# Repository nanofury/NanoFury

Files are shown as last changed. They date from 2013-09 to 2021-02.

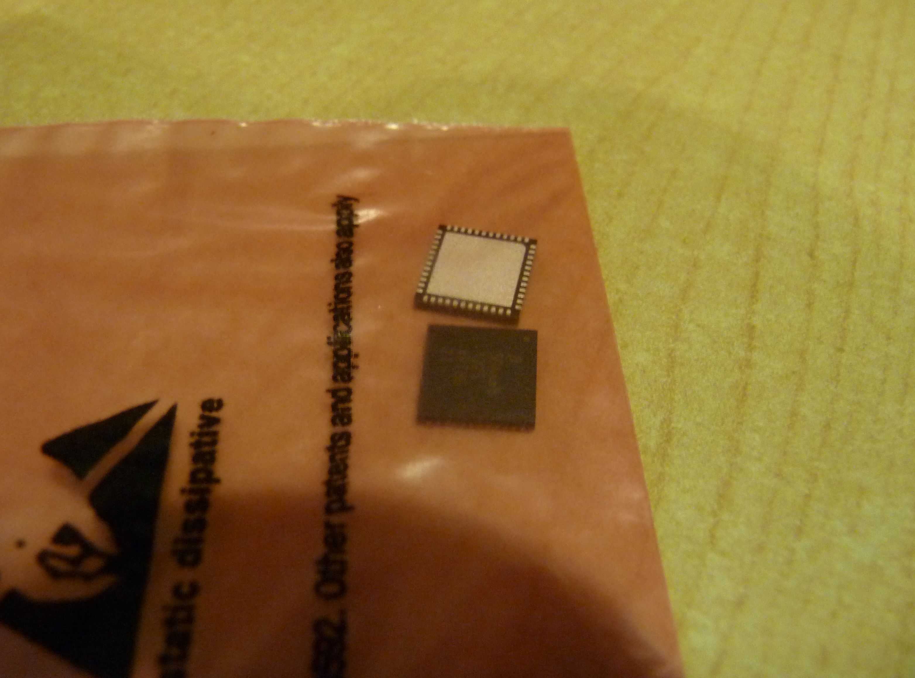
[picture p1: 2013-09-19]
NF1/docs/bitfury/img/P1060710m.jpg

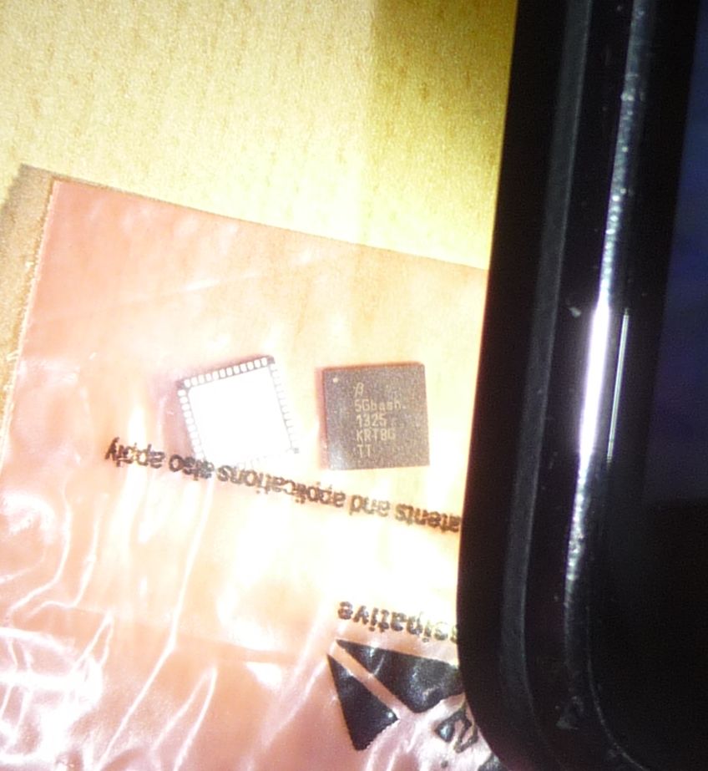
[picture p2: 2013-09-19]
NF1/docs/bitfury/img/P1060713m.jpg

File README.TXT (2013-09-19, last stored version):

NanoFury
========

NanoFury Bitcoin ASIC Miner Project

WARNING:

  This project is incomplete and in progress. There may be errors, mistakes, incomplete portions at this time. Do NOT use these project files to order circuit boards until they have been finished and confirmed to work.

  See LICENSE and COPYING files for terms and warranty disclaimer.

  See RELEASE NOTES for known problems, and issues.

SUMMARY:

  This is an open source effort to design and build a Bitcoin mining board based on the BitFury ASIC. Initially the goal is to have a simple USB-to-BitFury interface. The final goal is this design to be used as a base for a board with multiple ASIC chips as BitFury's chips are easily chain-able. The only limitation would be from the speed of the SPI bus which is estimated at this time to be sufficient for up to 64 chips.

STATUS:

  This project is under active development.

  A new cgminer-nanofury repo will be created for development with only changed files echoed here in the cgminer directory.

TODO:

  Adapt Kerry Wong's MCP2210 library for use with cgminer (unless Con Kolivas recommends another library - which may happen rather sooner than later as he mentioned that he has his own USB-HID library)

  Integration and debugging of the MCP2210 and BitFury chips.

  Stress testing and reliability in over-clocking situations.

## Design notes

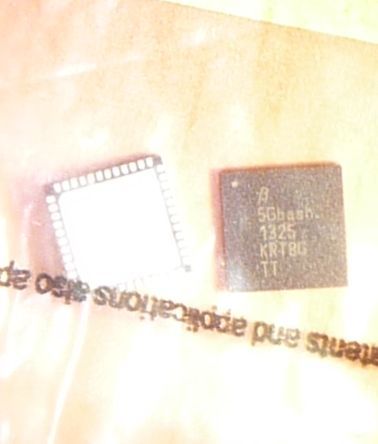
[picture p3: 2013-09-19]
NF1/docs/bitfury/img/P1060713a.jpg

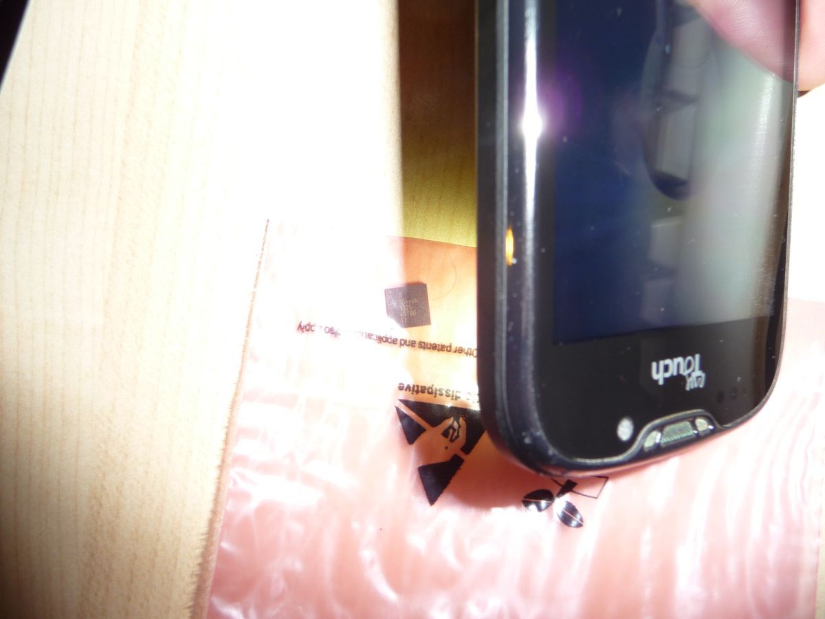
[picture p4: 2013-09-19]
NF1/docs/bitfury/img/P1060712m.jpg

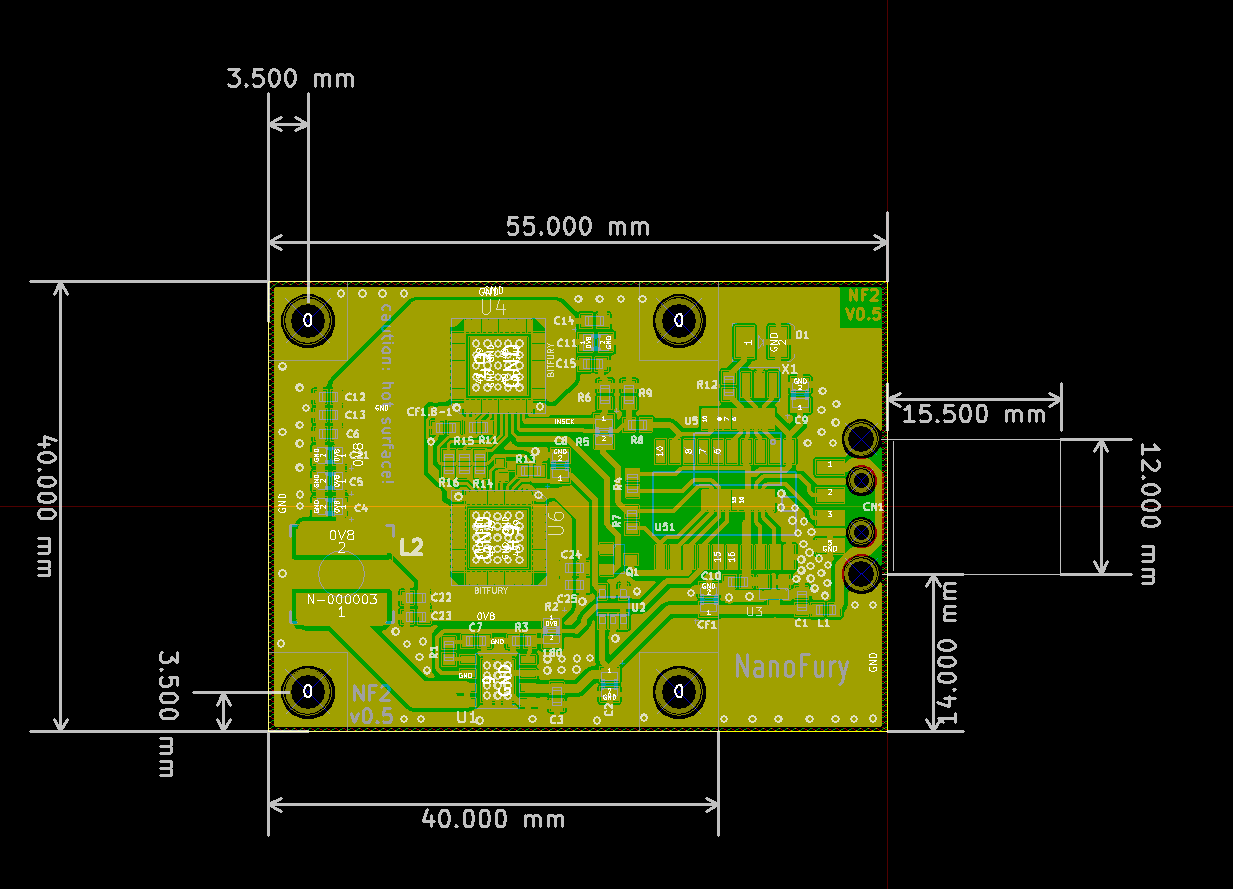
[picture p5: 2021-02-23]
NF1/kicad/NF2-MCP-V05/NF2-05-Dimensions.png

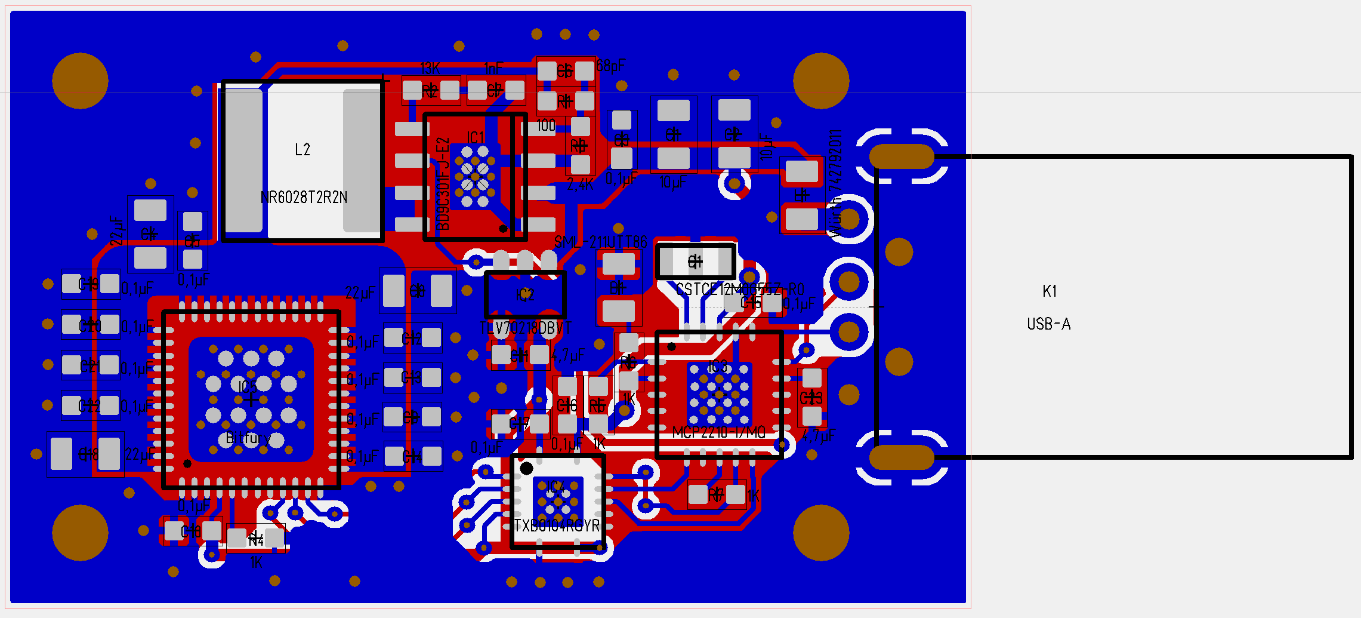
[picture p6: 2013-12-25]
NF1/kicad/NF1-MCP-V06-2/Nanofury2_Layout.PNG

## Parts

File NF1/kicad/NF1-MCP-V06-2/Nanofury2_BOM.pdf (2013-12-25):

Pos Anzahl Name | Wert | Gehäuse
1 | 1 | R1 | 100R/0,1%/25ppm | 0603_NORM | A102330CT-ND
2 | 4 | R4,R5,R6,R7 | 1K/1% | 0603_NORM | P1.00KHCT-ND
3 | 1 | R2 | 13K/1% | 0603_NORM | P13.0KHCT-ND
4 | 1 | R3 | 2,4K/0,1%/25ppm | 0603_NORM | P2.4KDBCT-ND
5 | 1 | L1 | | 0805_NORM | 732-4635-1-ND
6 | 2 | C11, C23 | 4,7µF/10V/X6S | 0603_NORM | 445-7442-1-ND
7 | 2 | C1,C2 | 10µF/25V/X6S | 0805_NORM | 445-14484-1-ND
8 | 1 | C7 | 1nF/50V/C0G | 0603_NORM | 1276-1091-1-ND
9 | 14 | C3,C5,C9,C10,C12,C13,C14,C15,C16,C17,C19,C20,C21,C22 | 0,1µF/16V/X7R | 0603_NORM | 1276-1005-1-ND
10 | 3 | C4,C8,C18 | 22µF/4V/X7U | 0805_NORM | 490-6468-1-ND
11 | 1 | C6 | 68pF/50V/C0G | 0603_NORM | 311-1067-1-ND
12 | 1 | IC1 | BD9C301FJ-E2 | SO8_SOT96-1_EP | 846-1117-1-ND
13 | 1 | IC5 | | QFN48/BITFURY | vorhanden
14 | 1 | IC3 | MCP2210-I/MQ | QFN20(5X5) | MCP2210-I/MQ-ND
15 | 1 | L2 | NR6028T2R2N | NR6028 | 587-2098-1-ND
16 | 1 | D1 | SML-211UTT86 | 0805_NORM | 511-1292-1-ND
17 | 1 | IC2 | TLV70218DBVT | SOT23/5 | 296-27889-1-ND
18 | 1 | IC4 | TXB0104RGYR | QFN20/TXB0104 | 296-21930-1-ND
19 | 1 | Q1 | CSTCE12M0G55Z-R0 CSTCE12M0G55Z-R0 | 490-1220-1-ND
20 | 1 | Leiterplatte
21 | 1
22 | 2 | | SK551-50-SA

DigiKey

Würth 742792011

Bitfury

USB-A-Stecker, PCB-Montage Kühlkörper Fischer-Electronic

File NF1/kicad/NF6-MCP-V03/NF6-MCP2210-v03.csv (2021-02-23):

ref | value | datasheet | footprint | Field1 | Field2 | Field3 | Field4 | Field5 | Field6 | Field7 | Field8
BF0 | BITFURY |  | QFN48
BF1 | BITFURY |  | QFN48
BF2 | BITFURY |  | QFN48
BF3 | BITFURY |  | QFN48
BF4 | BITFURY |  | QFN48
BF5 | BITFURY |  | QFN48
C1 | 100nF |  | 0603
C01 | 4.7uF |  | 0805 |  | AMK212AC6226MG
C02 | 100nF |  | 0603
C03 | 100nF |  | 0603
C04 | 100nF |  | 0603
C9 | 4.7uF/10V |  | 0805 |  | LMK212AB7106MG
C10 | 100n |  | 0603
C11 | 4.7uF |  | 0805 |  | AMK212AC6226MG
C12 | 100nF |  | 0603
C13 | 100nF |  | 0603
C14 | 100nF |  | 0603
C21 | 4.7uF |  | 0805 |  | AMK212AC6226MG
C22 | 100nF |  | 0603
C23 | 100nF |  | 0603
C24 | 100nF |  | 0603
C31 | 4.7uF |  | 0805 |  | AMK212AC6226MG
C32 | 100nF |  | 0603
C33 | 100nF |  | 0603
C34 | 100nF |  | 0603
C41 | 4.7uF |  | 0805 |  | AMK212AC6226MG
C42 | 100nF |  | 0603
C43 | 100nF |  | 0603
C44 | 100nF |  | 0603
C51 | 4.7uF |  | 0805 |  | AMK212AC6226MG
C52 | 100nF |  | 0603
C53 | 100nF |  | 0603
C54 | 100nF |  | 0603
C_REF0 | 100nF |  | 0603
C_REF1 | 100nF |  | 0603
C_REF2 | 100nF |  | 0603
C_REF3 | 100nF |  | 0603
C_REF4 | 100nF |  | 0603
C_REF5 | 100nF |  | 0603
CF1 | 4.7uF/10V |  | 0805 |  | C2012X6S0J226M085AC
CN1 | USB-A | 1001-011-01101.pdf | CNC-1001-011-01101 | 1001-011-01101.pdf | 1001-011-01101
D1 | LED | LO_LS_LY_T67K_Pb_free.pdf | 2PLCC | LO_LS_LY_T67K_Pb_free.pdf | LY T67K-J2M1-26-Z
F1 | FUSE 4A |  | 0603
L1 | 10R@100MHz/6A |  | 0603 |  | CIB10P100NC (or ACML-0603-060)
P0 | TP | ~ | ~ | ~
P1 | TP | ~ | ~ | ~
P2 | TP | ~ | ~ | ~
P3 | TP | ~ | ~ | ~
P4 | TP | ~ | ~ | ~
P5 | TP | ~ | ~ | ~
P51 | TP | ~ | ~ | ~
P52 | TP | ~ | ~ | ~
P53 | TP | ~ | ~ | ~
Q1 | BSS138L | BSS138LT1-D.pdf | SOT23 | BSS138LT1-D.pdf | BSS138LT3G
Q2 | Si2333CDS | si2333cd.pdf | SOT23 | si2333cd.pdf
R1 | 1k |  | 0603
R2 | 1k |  | 0603
R3 | 1k |  | 0603
R04 | 1k |  | 0603
R4 | 2k |  | 0603
R05 | 1k |  | 0603
R5 | 2k |  | 0805
R6 | 20k |  | 0603
R7 | 1k |  | 0603
R8 | 2K |  | 0603
R9 | 20k |  | 0603
R11 | 1k |  | 0603
R12 | 1k |  | 0603
R13 | 1k |  | 0603
R14 | 1k |  | 0603
R15 | 1k |  | 0603
R21 | 1k |  | 0603
R22 | 1k |  | 0603
R23 | 1k |  | 0603
R24 | 1k |  | 0603
R25 | 1k |  | 0603
R31 | 1k |  | 0603
R32 | 1k |  | 0603
R33 | 1k |  | 0603
R34 | 1k |  | 0603
R35 | 1k |  | 0603
R41 | 1k |  | 0603
R42 | 1k |  | 0603
R43 | 1k |  | 0603
R51 | 1k |  | 0603
R52 | 1k |  | 0603
R53 | 1k |  | 0603
R54 | 1k |  | 0603
R55 | 1k |  | 0603
U3 | LDO - 3.3V | 202250A.pdf | SOT23 | 202250A.pdf | MCP1700T-3302E/TT
U5 | MCP2210-I/SS | 22288A.pdf | SSOP-20 | 22288A.pdf
U51 | MCP2210-I/SO | 22288A.pdf | SOIC20 | 22288A.pdf
X1 | 12MHz | p16e.pdf | CSTCE_G15C | p16e.pdf | CSTCE12M0G55Z-R0

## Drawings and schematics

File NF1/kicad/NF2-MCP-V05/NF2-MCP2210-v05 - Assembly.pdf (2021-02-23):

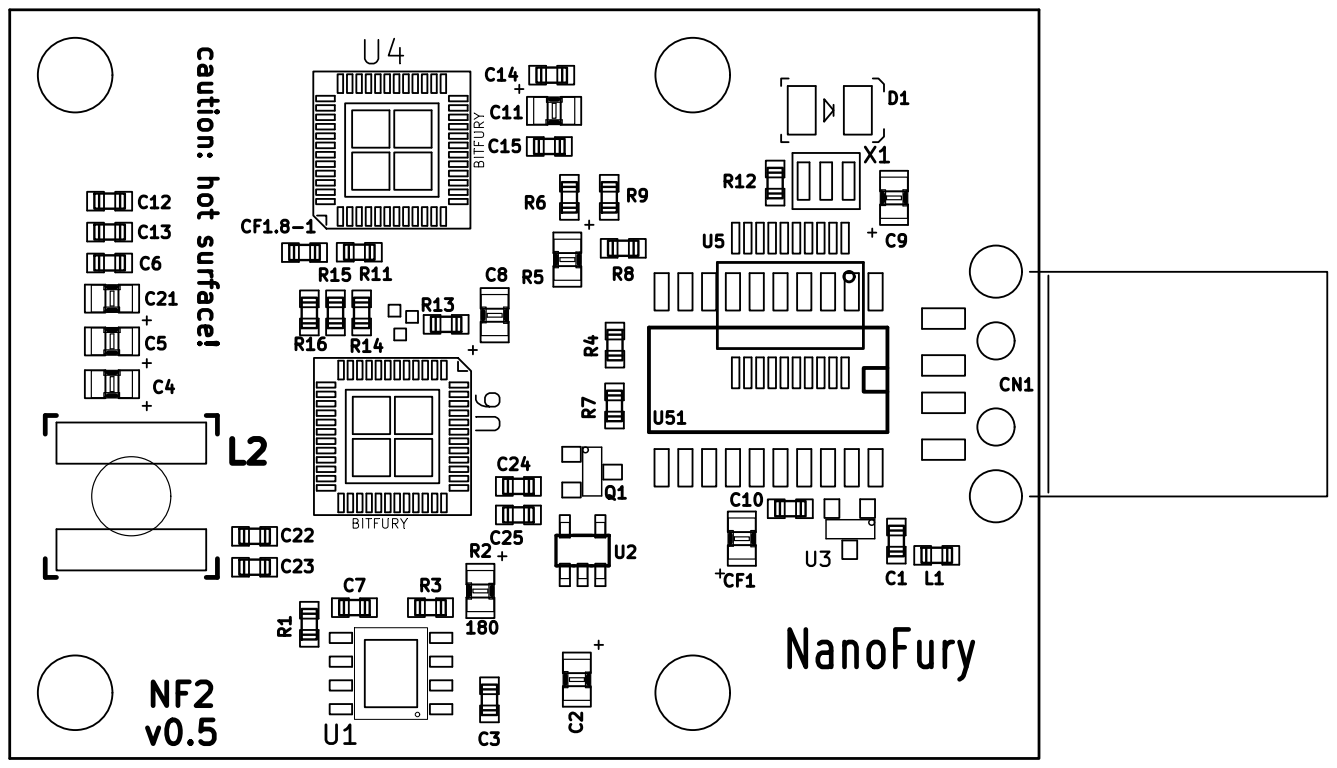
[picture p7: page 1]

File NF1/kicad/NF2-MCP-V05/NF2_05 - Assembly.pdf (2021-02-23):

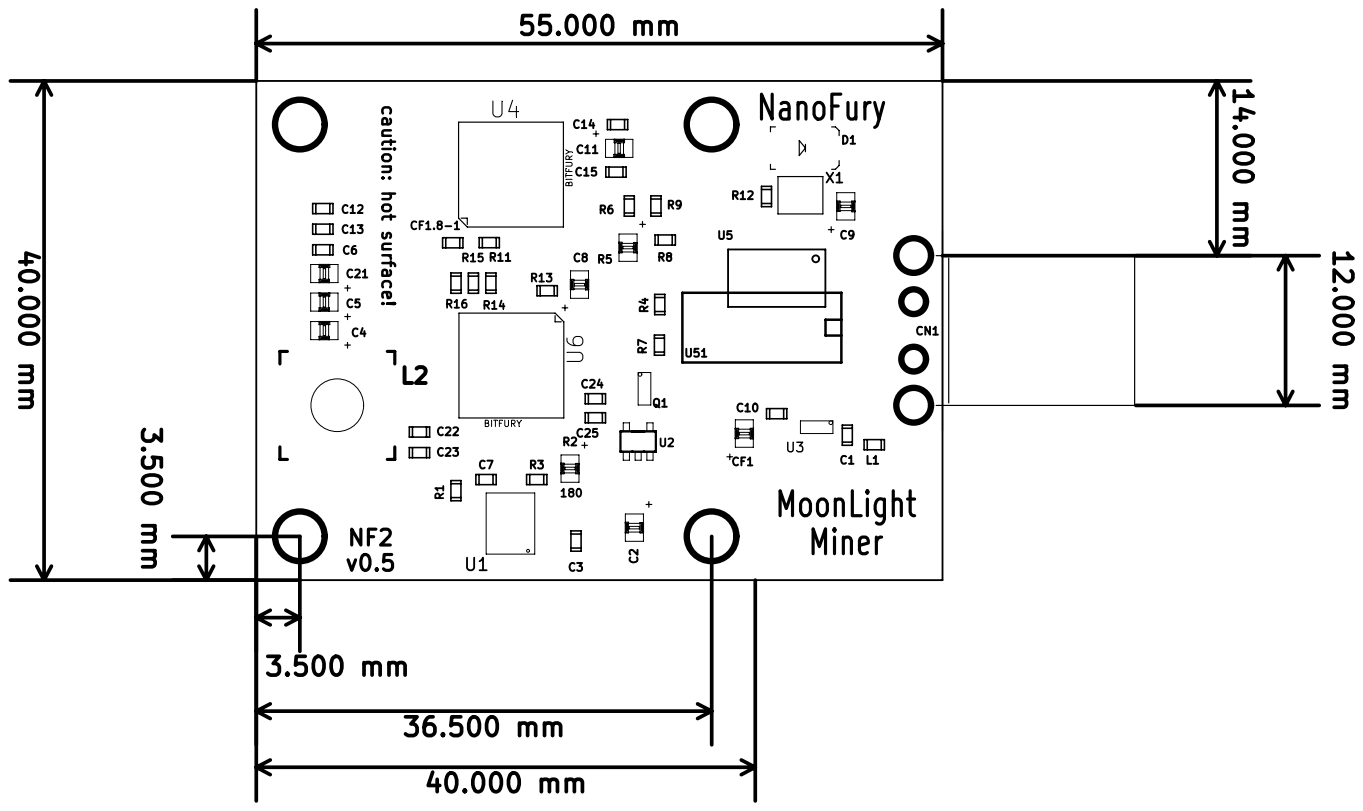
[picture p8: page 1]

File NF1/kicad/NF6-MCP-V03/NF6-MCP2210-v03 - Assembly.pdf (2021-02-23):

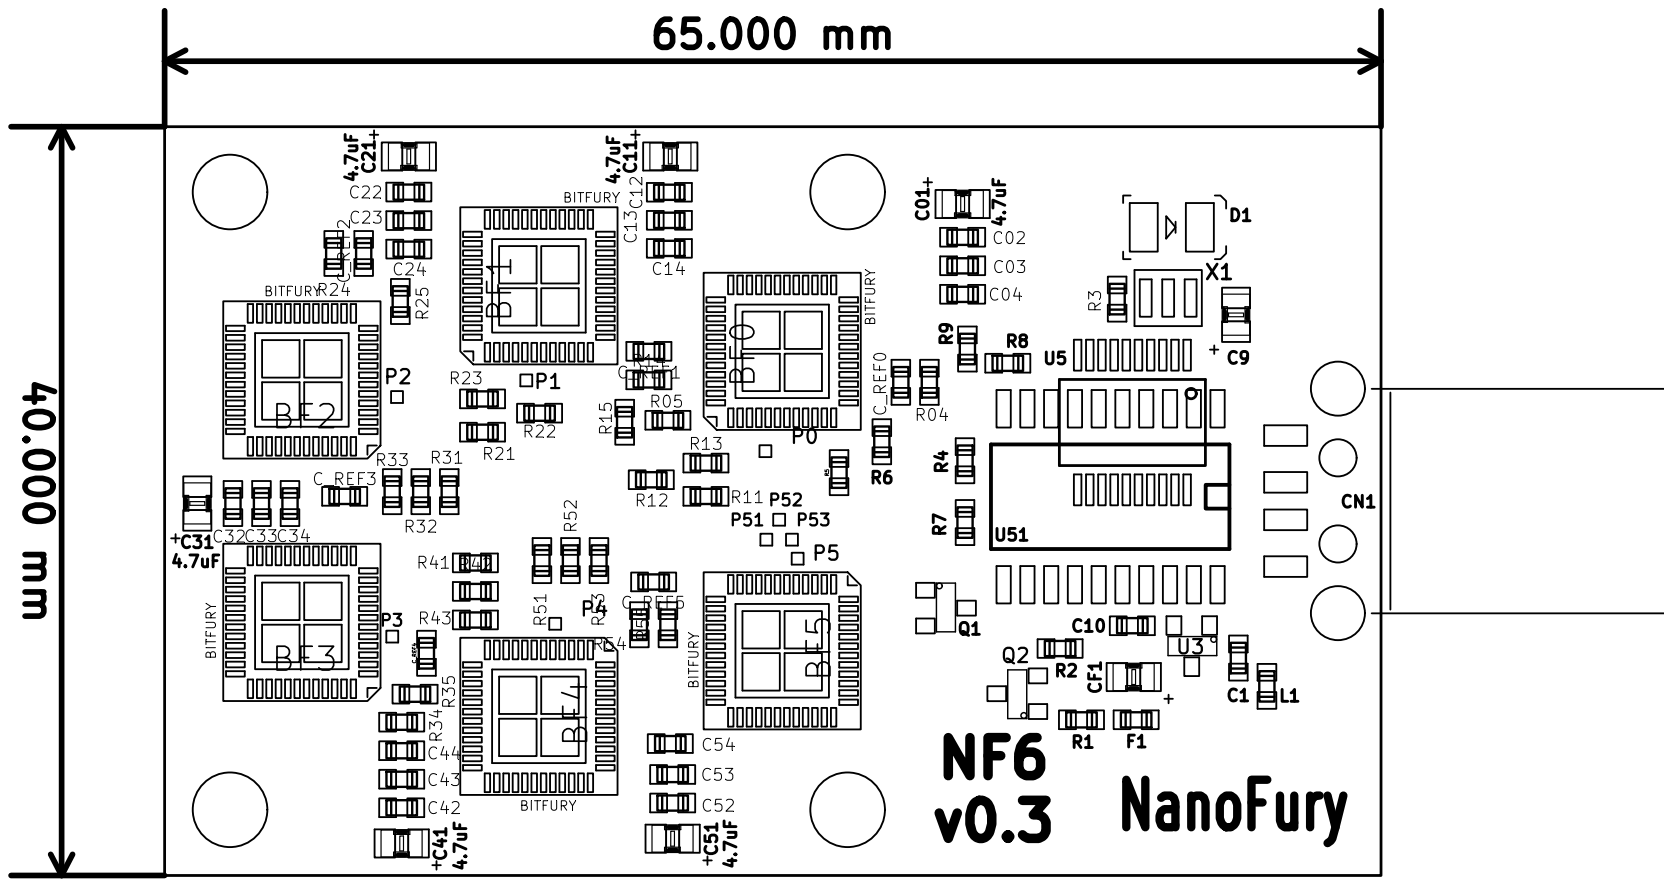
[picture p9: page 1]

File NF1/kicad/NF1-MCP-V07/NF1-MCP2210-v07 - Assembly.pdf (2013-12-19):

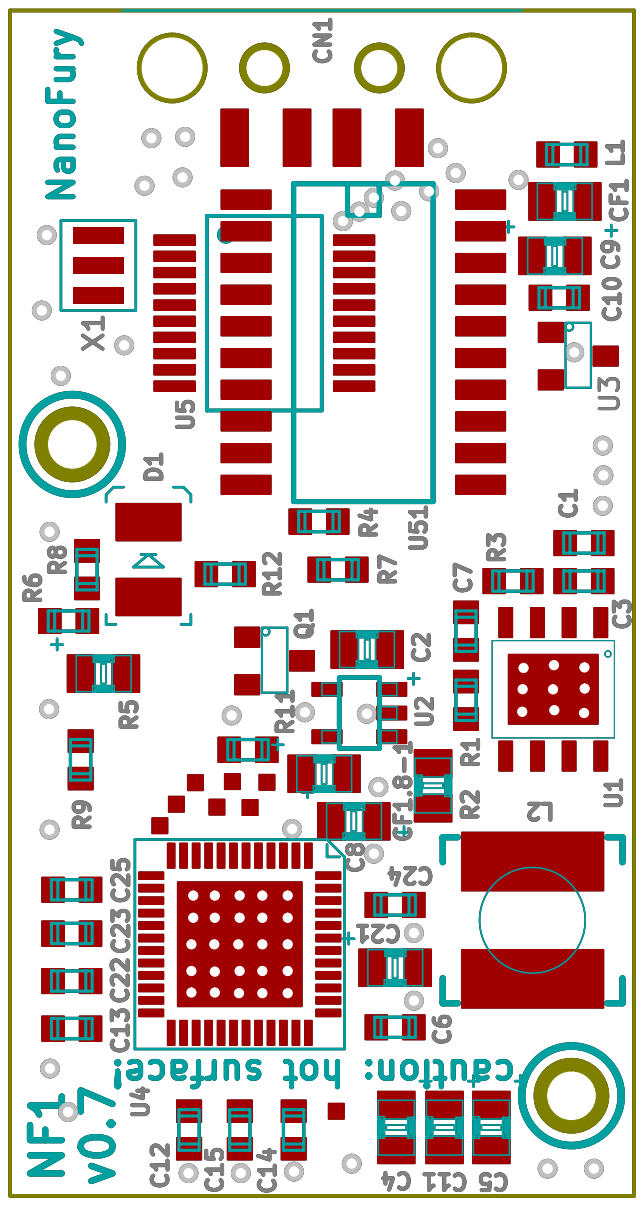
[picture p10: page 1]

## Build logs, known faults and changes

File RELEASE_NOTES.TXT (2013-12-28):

Release Notes

------------------------------------------------------------------------------
Dec 24, 2013 - NF1 Board - v0.7
Minor updates to schematics:
- add alternative package option for MCP2210
- core voltage bumped from 0.83V to 0.86V
PCB rework:
- Add footprints for both MCP2210-I/SO and MCP2210-I/SS (so that either of the two can be used)
- move around bulky capacitors so that they don't interfere if someone wants to add an extra heatsink on the bitfury chip.
- other minor component updates

------------------------------------------------------------------------------
Oct 01, 2013 - NF1 Board - v0.6
Minor updates to schematics:
- cleanup components
- update component sizes
PCB rework:
- fix erroneous USB connector pads numbering (and also holes diameter)
- update 0630 pads (as the real ones are a bit bigger)
- other minor component updates

------------------------------------------------------------------------------
Sep 23, 2013 - NF1 Board - v0.5
- Add 1.8->3.3v converter (using a BSS138L MOSFET transistor)
- add SOT-23 package to library
- add MOS-N (and MOSFET-N) components to library
- add TechnoBit's logo for boards for Marto74

------------------------------------------------------------------------------
Sep 20, 2013 - NF1 Board - v0.4
- add 0603 and fix most capacitors & resistors to that size (0805 just takes too much valuable space)
- add LED
- replace PCB-printed USB connector with a USB-A plug
- PCB has ZERO traces on the back! :)
- add/update some components (wrong pads, missing 3d models, etc minor tweaks)

------------------------------------------------------------------------------
Sep 18, 2013 - NF1 Board - v0.3

- Fixed all capacitors & resistors to 0805 package (as 0402 is just too much pain and no gain)
- Added PWR_ENABLE control signal to turn on/off power to BitFury chip
- fixed BF chip solder paste mask (to 4 smaller squares as 1 big square is a bit too much and solder leaks all over the place)
- No more (than the bare possible minimum) tracks underneath the board
- fix bottom solder mask to uncover USB connector
- fix MCP2210's missing GND connection

------------------------------------------------------------------------------
Aug 20, 2013 - NF1 v0.2

- replace 1.8V LDO

------------------------------------------------------------------------------
Aug 3, 2013 - NF1 v0.1

- Rework schematic to use MCP2210
- add 3rd power regulator for 3.3V (providing power to MCP2210)

------------------------------------------------------------------------------
Jul 23, 2013 - Project Start - NF1 v0.0.1

Initial design of both board and schematic.

Initially based on FT232RL chip (and manually drive all pins - SCK, MOSI and MISO)

Some of the kicad files originated from BKKCoin's K1 Nano files (which originated from Eagle CAD files through a conversion). Majority of the converted files however had to be reworked as they were unusable, had bad drawings, pins (size/position/etc).

BKKCoin's words: "My recommendation: if you ever find yourself using Eagle and wanting to use Kicad - start over fresh, do not convert."

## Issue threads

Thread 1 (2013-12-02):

nf1_init assertion

IL2, 2013-12-02:
On exit from test running, assertion happens:

---
## Microsoft Visual C++ Debug Library

Debug Assertion Failed!

Program: D:\devother\NanoFury_Init\Debug\nf1_init.exe
File: f:\dd\vctools\crt_bld\self_x86\crt\src\wcstol.c
Line: 94

Expression: nptr != NULL

Console:
D:\devother\NanoFury_Init\Debug>nf1_init.exe test 0000071189
nf1_init.exe [command] [setting]
Commands:
test [device serial number] - runs bitfury tests to that device
fixID [ignored] - Tests for NanoFury devices and fixes Product String

test mode specified for device 0.

Testing device 1 : SERIAL=0000071192,  Path=[\?\hid#vid_04d8&pid_00de#7&3f20ef1&0&0000#{4d1e55b2-f16f-11cf-88cb-001111000030}]
NanoFury Test: PASS, Product String=[NanoFury NF1 v0.6], Manufacturer=[Microchip Technology Inc.]
Testing device 2 : SERIAL=0000071189,  Path=[\?\hid#vid_04d8&pid_00de#7&dca25a2&0&0000#{4d1e55b2-f16f-11cf-88cb-001111000030}]
DEVICE FOUND! Proceeding with testing... Press ESC to cancel testing at any time

FOUND VALID SOLUTION f0c4e61f MIDSTATE0 b0e72d8e NONCE (TV) f0c4e61f BUF c819f1f1 @ 1903 mS [0:22:9]
FOUND VALID SOLUTION f0c4e61f MIDSTATE0 b0e72d8e NONCE (TV) f0c4e61f BUF c819f1f1 @ 0016 mS [0:22:9]
FOUND VALID SOLUTION f0c4e61f MIDSTATE0 b0e72d8e NONCE (TV) f0c4e61f BUF c819f1f1 @ 0015 mS [0:22:9]
FOUND VALID SOLUTION cb0b5c9d MIDSTATE0 0cad7cd1 NONCE (TV) cb0b5c9d BUF b44ea1cb @ 1451 mS [0:22:10]
FOUND VALID SOLUTION cb0b5c9d MIDSTATE0 0cad7cd1 NONCE (TV) cb0b5c9d BUF b44ea1cb @ 0016 mS [0:22:10]
FOUND VALID SOLUTION cb0b5c9d MIDSTATE0 0cad7cd1 NONCE (TV) cb0b5c9d BUF b44ea1cb @ 0015 mS [0:22:10]
FOUND VALID SOLUTION d104ec4b MIDSTATE0 bfeb8d06 NONCE (TV) bfdba262 BUF c88dbcd1 @ 1435 mS [0:22:12]
FOUND VALID SOLUTION 7950e001 MIDSTATE0 bfeb8d06 NONCE (TV) bfdba262 BUF c201e879 @ 0016 mS [0:22:12]
FOUND VALID SOLUTION 5abb2e01 MIDSTATE0 bfeb8d06 NONCE (TV) bfdba262 BUF 371da85b @ 0016 mS [0:22:12]
FOUND VALID SOLUTION 5abb2e01 MIDSTATE0 bfeb8d06 NONCE (TV) bfdba262 BUF 371da85b @ 0000 mS [0:22:12]
FOUND VALID SOLUTION d104ec4b MIDSTATE0 bfeb8d06 NONCE (TV) bfdba262 BUF c88dbcd1 @ 0015 mS [0:22:12]
FOUND VALID SOLUTION cf962e08 MIDSTATE0 40fe79e6 NONCE (TV) cf962e08 BUF 1a1d0cd0 @ 1560 mS [0:22:13]
FOUND VALID SOLUTION cf962e08 MIDSTATE0 40fe79e6 NONCE (TV) cf962e08 BUF 1a1d0cd0 @ 0016 mS [0:22:13]

Closed 2021-02-23.

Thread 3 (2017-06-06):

is there any implementation to useNF2 whit python

MirkoPerrone, 2017-06-06:
Hi i'm wondering if there is any kind of implementation of NF2 for python ... Im asking couse i want tu use nf2 in my python program but i can not know how to access to NF2 , is there any API or Driver  o Library to use in python or any other proramming languages

vstrinski, 2017-06-07:
Can you please elaborate on "how to access NF2"? Are you looking for low-level access to the bitfury chips? Or something else?
If you want low-level access you can use the provided sample C code which is part of the project. This code was used in one form or another as the driver that's embedded in bfgminer and cgminer.
Or if you are looking for obtaining stats and other similar high-level access to the mining software then you can use the API provided by bfgminer or cgminer or whichever software you use.
Let me know please if this answered your question.

Closed 2021-02-23.

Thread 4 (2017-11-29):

Some help

PEVN, 2017-11-29:
After reading the thread I have two questions...
,1) can I build the H and M boards along with a power supply, connect them together and have an operational miner?
2) Would these schematics work with the new bitfury chip?

vstrinski, 2017-11-29:
Hello,

you've probably located the wrong project - this one doesn't have "H and M boards" (and to be honest I am not sure which boards you are referring to).

As for the second part - the schematics were meant to work with a very specific chip. They will not work with another chip.

Closed 2017-11-29.

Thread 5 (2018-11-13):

Help on Building

yacobtsige, 2018-11-13:
hi guys im trying this project with my friends , and I was wondering how I can make it im new to this and I was hoping if you guys could show me

MirkoPerrone, 2018-11-26:
Ehy Hi, what it is about ? I can help if it is an interesting project.
Keep me posted, bye 👍

yacobtsige, 2018-11-26:
well the hole project is to show you how to build your own usb miner , I couldn't find a bitfury asic chip I contacted them but they said 50000 chips is min. order any ideas

Vallerik, 2021-01-31:
Hey! I join the question, where can you buy an ASIC chip?

yacobtsige, 2021-01-31:
Well i asked that question a long while ago and found out 2 things
1.finding the chips they use is really hard and even if you find it they might not give you the datasheet of their ASIC chips
2. Their greedy they make millions selling the stuff and they hate the idea of losing profit so they don't give out any info

but if you are committed then your options are either to buy an old asic miner break it apart and start experimenting or order 50Kchips from bitfury and ask them to help you . They state that they will help your hardware development but either way i personally abandoned all hopes on this but i hope you find something useful and interesting also check on alibaba their shady but some sell old asic chips good luck

Vallerik, 2021-02-02:
It's a shame that it turns out this way .. I want to make my own miner, are there any similar projects? Which can be repeated? Another Usb miner project?

nanofury, 2021-02-23:
Hello, first - I applaud your desire to give this project a try. However, keep in mind that it was developed so long ago that even if you could find the chips and everything it would still not be a viable product.

Then, at the root of the project are the Bitfury chips. They were hard to get even back then.

They are no longer available (and haven't been available for many years). They were efficient back in the days, but with the bitcoin difficulty jumping multiple orders of magnitude the chips are no longer feasible.
You might find other and more modern chips, but they would almost certainly require a completely new design.

However, if you do find some other chips that you would like to experiment with - this project could serve as a good base design. Feel free to experiment!

Good luck!

Closed 2021-02-23.

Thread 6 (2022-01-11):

Bitfury chip

NicoGas2001, 2022-01-11:
Hi, my name is Niccolò
Where can i find the Bitfury QFN48 chip?
Can it be replaced by another chip on te market?
I have found the Bm1387 antminer chips,but I don't think they can be implemented without making changes to the pcb, can you say something about it?

Tanks @nanofury

BastelPichi, 2022-07-14:
This project is old, 2ghs is nothing nowadays...
Different chip takes redesign of course

vstrinski, 2022-07-17:
BastelPichi is correct - the chip is (beyond) obsolete. It was last manufactured almost 10 years ago. There is no new supply of those chips.
Any new chip would require a new design.

Closed 2022-07-17.

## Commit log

2013-09-19 Initial commit of the NanoFury project
    add board versions 0, 0.1, 0.2 and 0.3
    [NF1-BLANK.brd, NF1-MCP2210-v02.kicad_pcb, NF1-MCP2210-v02.sch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]
2013-09-19 update part numbers
    [NF1-MCP2210-v03.sch]
2013-09-20 update pcb components
    minor tweaks and fixes; add 3d models
2013-09-20 add new components (for v0.4)
    add 0603, LED and USB-A plug
    add PDFs
2013-09-20 PCB Version 0.4
    [NF1-MCP2210-v04.kicad_pcb, NF1-MCP2210-v04.sch]
2013-09-20 minor fixes
    [NF1-MCP2210-v04.kicad_pcb]
2013-09-23 NanoFury NF1 - PCB Version 5
    Add 1.8->3.3v converter (using a BSS138L MOSFET transistor)
    add SOT-23 package to library
    add MOS-N (and MOSFET-N) components to library
    [NF1-MCP2210-v05.kicad_pcb, NF1-MCP2210-v05.sch]
2013-09-24 Add TechnoBit logo
    Add TechnoBit logo for Marto74
    [NF1-MCP2210-v05.kicad_pcb]
2013-09-24 More tweaking with TechnoBit's logo
    [NF1-MCP2210-v05.kicad_pcb]
2013-09-27 Add a separate copy for TechnoBit
    update SCH version number and other minor tweaks
    [NF1-MCP2210-v05-TechnoBit.kicad_pcb, NF1-MCP2210-v05.sch]
2013-09-28 Adjust PCB silkscreen options
    display component references and part values
    update font and position
    [NF1-MCP2210-v05.kicad_pcb]
2013-10-02 NanoFury NF1 - PCB v0.6
    Minor updates to schematics:
    - cleanup components
    - update component sizes
    PCB rework:
    - fix erroneous USB connector pads (and also holes diameter)
    - update 0630 pads (as the real ones are a bit bigger)
    - other minor component updates
    [NF1-MCP2210-v06-TB.kicad_pcb, NF1-MCP2210-v06.kicad_pcb, NF1-MCP2210-v06.sch]
2013-10-05 Minor updates to SCH and PCB
    Update component references, use 105C+ rated whenever possible
    Add new components PDFs
    Update PCB component pads:
    - 3.3V LDO change from SC-59 to SOT-23
    - fix 0630 pads
    [NF1-MCP2210-v06-TB.kicad_pcb, NF1-MCP2210-v06.kicad_pcb, NF1-MCP2210-v06.sch]
2013-10-07 Add PCB drawing and dimensions (including heatsink holes position) NOTE: holes would likely end up being a 0.1mm smaller if/when they get metalized.
2013-11-22 Add v0.7 schematic
    [NF1-MCP2210-v07.sch]
2013-12-17 NanoFury NF1 - PCB v0.7
    PCB rework version 0.7
    - add support for both footprints - MCP2210-I/SO and MCP2210-I/SS
    - component cleanup and rearrangement
    - tweak default voltage to 0.86V (from 0.83)
    [NF1-MCP2210-v07.kicad_pcb]
2013-12-19 add PCB 0.7 assembly drawings
2013-12-24 added schematic
2013-12-28 Add NF1 Board 0.7 notes
2013-12-28 Update current hadware version (to NF1 PCB 0.7)
2021-02-23 NanoFury Project Wrap-up
    Final commit with NF1, NF2, and NF6 variants and various build versions.
    [NF1-MCP2210-v07-CryptoRig.kicad_pcb, NF1-MCP2210-v07-MoonLightMiner.kicad_pcb, NF1-MCP2210-v07-TechnoBit.kicad_pcb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]
